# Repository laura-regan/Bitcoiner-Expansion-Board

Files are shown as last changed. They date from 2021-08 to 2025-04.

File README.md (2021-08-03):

# Bitcoiner Expansion Board

This repository contains the Altium Designer project for an expansion board for the [EBAZ4205](https://github.com/xjtuecho/EBAZ4205) bitcoin miner board which contains a Zynq 7010 SoC+FPGA. The purpose of the board is to expand the functionality of the bitcoin miner, allowing easy access to the Zynqs PL (Programmable Logic) pins via PMOD connectors and provide a HDMI output so that the board can be used for image processing research. The board also includes four switches and a two digit seven segment display to be used for debugging of the board and also to be used by students in a introductory digital design class. To facilitate programming and debugging of the FPGA and ARM processor a FT2232H based JTAG programmer was included on the board. The FT2232H chip has two channels and the second is used as a UART connection to allow communication between the ARM processor and a PC. 

The board also has a buck converter allowing it to be powered by a 12V power supply. A jump connector on the board allows the either USB or DC jack to be used as the power source.

The board has 4 layers and the stackup is the following:  
Layer 1: Signal  
Layer 2: GND  
Layer 3: GND  
Layer 4: Signal

Also included in the repository is a PDF of the schematic, PDFs of the PCB layout, a 3D PDF of the PCB, and the Gerber/NC Drill files for the PCB.

## PCB Renders
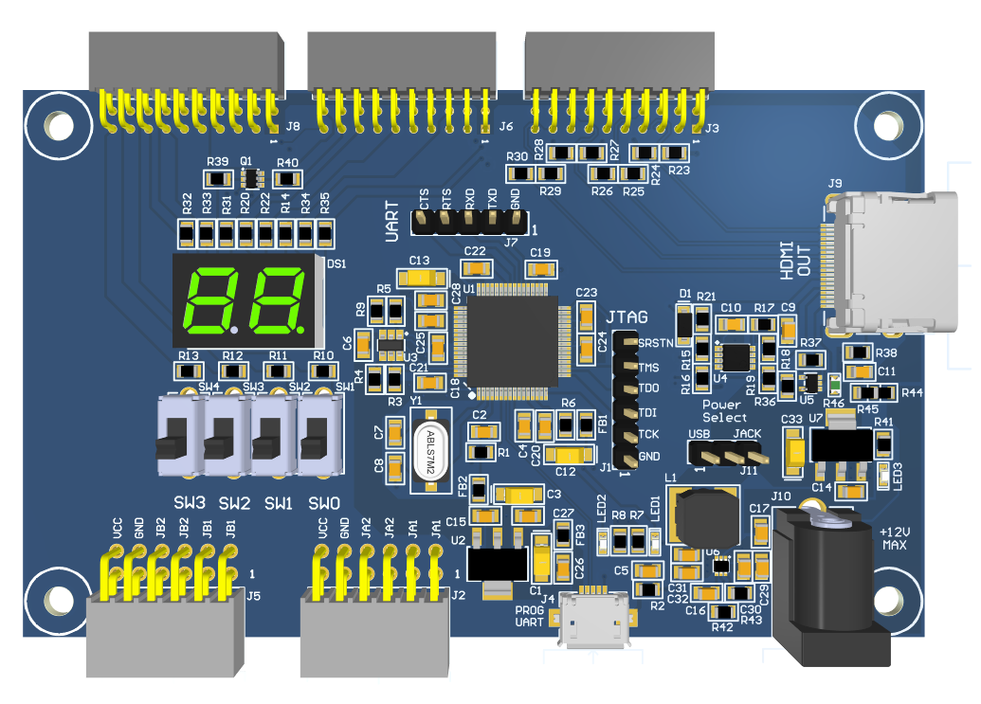
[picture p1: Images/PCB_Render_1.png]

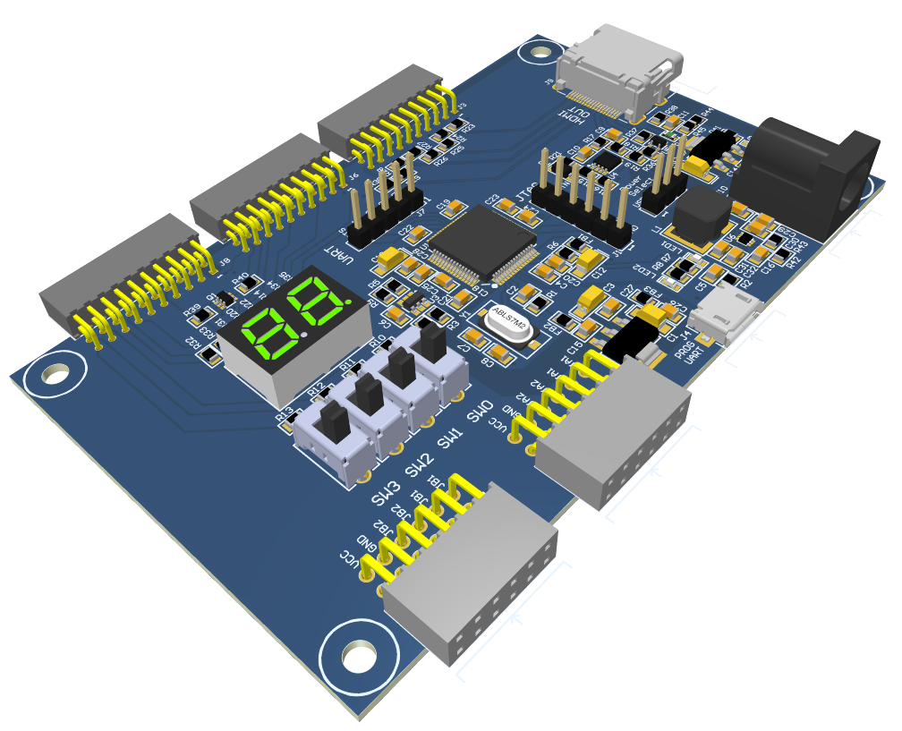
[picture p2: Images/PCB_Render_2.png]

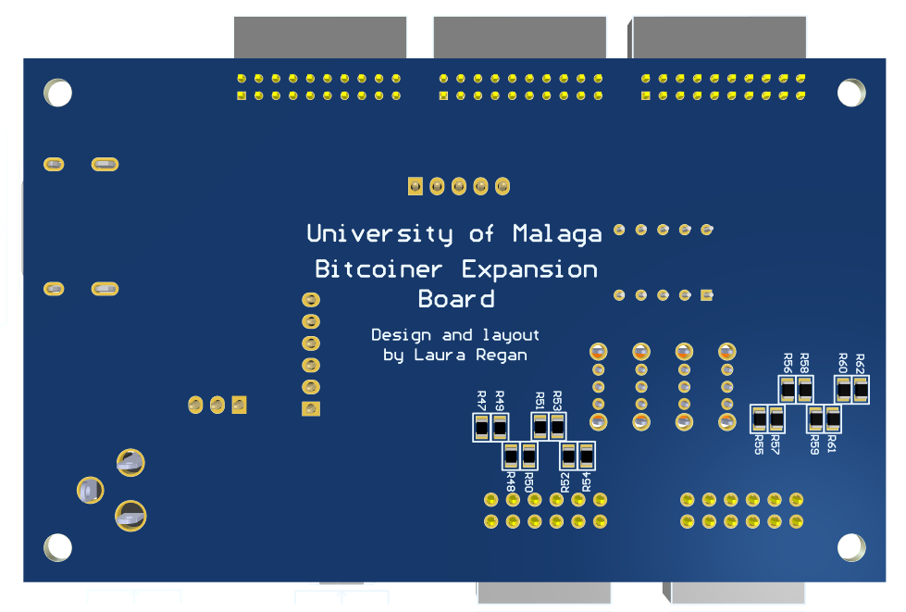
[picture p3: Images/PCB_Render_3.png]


## PCB Layout




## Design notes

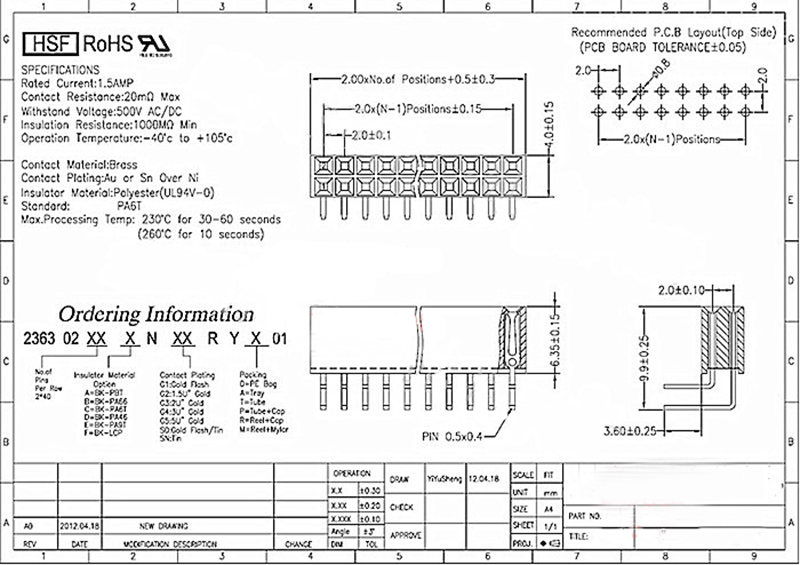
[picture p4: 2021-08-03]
Bitcoiner-Expansion-Board/Datasheets/Conector-Bitcoiner-2x10-2.0mm .jpg

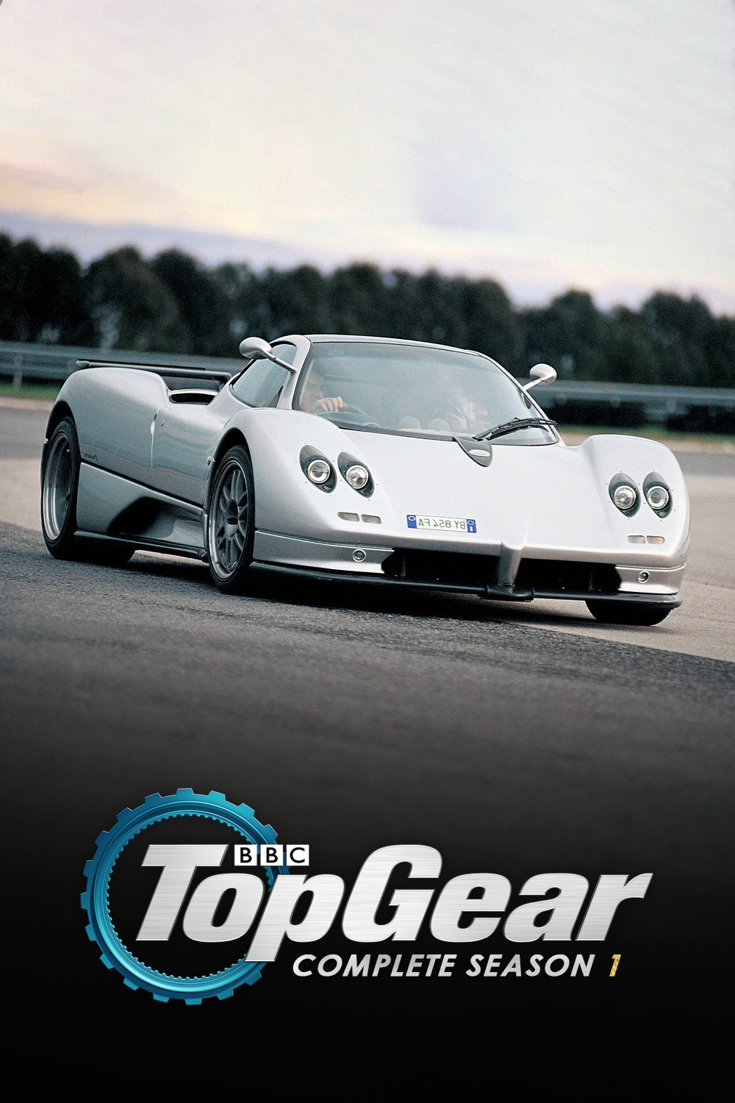
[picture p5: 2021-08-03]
Bitcoiner-Expansion-Board/Datasheets/Top Gear (2002) - Season 1.png

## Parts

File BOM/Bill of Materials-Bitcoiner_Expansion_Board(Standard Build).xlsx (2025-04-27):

Designator | Comment | Description | Manufacturer | Manufacturer Part Number | Quantity | Footprint
C1, C3, C12, C13, C33 | 4.7u / 16V | Tantalum capacitor 4.7 uF 16 VDC, T491A475K016AT, KEMET | KEMET | T491A475K016AT | 5 | C_TAN_A
C2, C4, C5, C6, C9, C10, C11, C16, C18, C19, C20, C21, C22, C23, C24, C25, C26, C27, C28, C30 | 100n | AVX - 08055C104KAT4A - Multilayer Ceramic Capacitor, 0.1 F, 10%, X7R, 50 V, 0805 [2012 Metric] RoHS Compliant: Yes | Kyocera AVX | 08055C104KAT4A | 20 | C0805
C7, C8 | 18p | Cap Ceramic 18pF 50V C0G 5% Pad SMD 0805 125°C Extreme Low ESR Bag | KEMET | C0805C180J5GAC | 2 | C0805
C14, C15 | 1u / 25V | Cap Ceramic 1uF 25V X7R 10% SMD 0805 125C Plastic T/R | KEMET | C0805C105K3RAC7210 | 2 | C0805
C17, C29 | 10u / 25V | CAP CER 10UF 25V X5R 0805 | Murata | GRM21BR61E106KA73K | 2 | C0805
C31, C32 | 22u / 10V | Cap Ceramic 22uF 10V X5R 20% SMD 0805 85C Cardboard T/R | Samsung | CL21A226MPCLRNC | 2 | C0805
D1 | BAS16GWJ | High-speed switching diode BAS16GW/SOD2/REEL 13 Q1/T1 S" | Nexperia | BAS16GWJ | 1 | SOD123
DS1 | LDD-E2802RD | Dual Digit 565 nm Green 0.28 inch Common Anode Seven Segment Display | Lumex | LDD-E2802RD | 1 | LDD-E2802RD
FB1, FB2, FB3 | 600R / 100MHz / 0.5A | TDK MMZ2012R601AT000 FERRITE BEAD, 0.2OHM, 500MA, 0805 | TDK | MMZ2012R601AT000 | 3 | R0805
J1 | HDR MALE 1x6 2.54MM |  | Amphenol | G800W302018EU | 1 | HDR_MALE_1X6_2.54MM
J2, J5 | SSW-106-02-T-D-RA | Connector | SAMTEC | SSW-106-02-T-D-RA | 2 | SSW-106-XX-YYY-D-RA
J3, J6, J8 | CON_2X10_2.0MM_RA |  |  |  | 3 | CON_2X10_2.0MM_RA
J4 | 10104111-0001LF | Conn USB Type A/B RCP 5 POS 0.65mm Solder RA SMD 5 Terminal 1 Port T/R | AMPHENOL ICC (FCI) | 10104111-0001LF | 1 | 101041110001LF
J7 | HDR MALE 1x5 2.54MM | HDR FEMALE 1x5 2.54MM | Amphenol ICC | 10129378-905001BLF | 1 | Hdr_Female_1x5_2.54mm
J9 | RAHHD19TR | HDMI Connector | Switchcraft Conxall | RAHHD19TR | 1 | RAHHD19TR
J10 | KLDX-0202-BC | Conn Power PIN 2 POS Solder RA Thru-Hole 3 Terminal 1 Port | Kycon | KLDX-0202-BC | 1 | KLDX-0202-BC
J11 | HDR 1x3 | HDR MALE 1x3 2.54MM | Amphenol | G800W305018EU | 1 | HDR_Male_1x3_2.54mm
L1 | 4.7u / 3.3A | Pwrind, SMT, Shld, Lrated / 6.0X6.0X4.5MM / Uom=ea / Wire Wound Inductive / Fixed Inductor | Laird Steward | TYS60454R7M-10 | 1 | TYS6045
LED1, LED2, LED3 | Amber | LED Uni-Color Amber 609nm Automotive 2-Pin Chip 0603(1608Metric) T/R | Inolux | IN-S63AT5A | 3 | LED0603
LINK1 | LINK | CONN SHUNT 2POS OPEN 2.54MM | TE Connectivity | 382811-8 | 1
Q1 | BC857BS,115 | NEXPERIA - BC857BS,115 - TRANSISTOR, DUAL, PNP, SC-88 | Nexperia | BC857BS,115 | 1 | SOT363
R1 | 12k | Res Thick Film 0805 12K Ohm 1% 0.125W(1/8W) ±100ppm/C Molded SMD Paper T/R | Yageo | RC0805FR-0712KL | 1 | R0805
R2, R3, R4, R5, R6, R10, R11, R12, R13, R36, R43 | 10k | RES SMD 10K OHM 1% 1/8W 0805 | Yageo | RC0805FR-0710KL | 11 | R0805
R7, R8, R41 | 470R | Res Thick Film 0805 470 Ohm 1% 1/8W +/-100ppm/ßC Molded SMD Paper T/R | Yageo | RC0805FR-07470RL | 3 | R0805
R9 | 2k | Res Thick Film 0805 2K Ohm 1% 1/8W 100ppm/C Molded SMD SMD Paper T/R | Yageo | RC0805FR-102KL | 1 | R0805
R14, R20, R22, R31, R32, R33, R34, R35 | 200R | Res Thick Film 2.0 x 1.2 mm 200 Ohm 1% 0.125W(1/8W) 100ppm/ C Molded SMD Paper T/R | Yageo | RC0805FR-07200RL | 8 | R0805
R15, R16, R18, R19 | 1.5k | Res Thick Film 0805 1.5K Ohm 1% 0.125W(1/8W) ±100ppm/C Molded SMD Paper T/R | Yageo | RC0805FR-071K5L | 4 | R0805
R17 | 200k | YAGEO - RC0805FR-07200KL - RES, THICK FILM, 200K, 1%, 0.125W, 0805, REEL | Yageo | RC0805FR-07200KL | 1 | R0805
R21 | 27k | Chip Resistor Precision Grade Thick Film 0805 27kOhm 1% Paper T/R | Yageo | RE0805FRE0727KL | 1 | R0805
R37 | 100k | YAGEO RC0805FR-07100KL RES, THICK FILM, 100K, 1%, 0.125W, 0805, REEL | Yageo | RC0805FR-07100KL | 1 | R0805
R38 | 1M | Res Thick Film 0805 1M Ohm 1% 0.125W(1/8W) ±100ppm/C Epoxy SMD T/R | Yageo Phycomp | RC0805FR-071ML | 1 | R0805
R39, R40 | 2.2k | RESISTOR, THICK FILM, 2.2KOHM, 125mW, 1%, FULL REEL | Yageo | RC0805FR-072K2L | 2 | R0805
R42 | 52.3k | Res Thick Film 0805 52.3K Ohm 1% 1/8W ±100ppm/°C Molded SMD SMD Paper Tape on Plastic Reel | Bourns | CR0805-FX-5232ELF | 1 | R0805
R45 | 0R | Res Thick Film 0805 0 Ohm Epoxy Pad SMD T/R | Yageo | RC0805FR-070RL | 1 | R0805
R46 | 0ZCM0012FF2G | PTC RESET FUSE 9V 120MA 0603 | Bel | 0ZCM0012FF2G | 1 | 0ZCM0012FF2G
R47, R48, R49, R50, R51, R52, R53, R54, R55, R56, R57, R58, R59, R60, R61, R62 | 200R | RES SMD 200 OHM 1% 1/10W 0603 | Panasonic | ERJ-3EKF2000V | 16 | R0603
SW1, SW2, SW3, SW4 | OS102011MS2QN1 | Slide | ITT C&K | OS102011MS2QN1 | 4 | OS102011MS2QN1
U1 | FT2232HL-REEL | Integrated Circuit | FTDI Chip | FT2232HL-REEL | 1 | QFP50P1200X1200X160-64N
U2, U7 | MCP1825ST-3302E/DB | IC REG LIN 3.3V 500MA SOT223-3 | Microchip | MCP1825ST-3302E/DB | 2 | SOT-223-3
U3 | 93LC56BT-I/OT | MICROCHIP - 93LC56BT-I/OT. - 2K, 128 X 16, SERIAL EE, IND ROHS COMPLIANT: YES | Microchip | 93LC56BT-I/OT | 1 | SOT-23-6
U4 | LSF0102DPH |  | Nexperia | LSF0102DPH | 1 | SOT505-2
U5 | 74LVC1G07GW,125 | NEXPERIA - 74LVC1G07GW,125 - BUFFER, NON-INVERTING, TSSOP-5 | Nexperia | 74LVC1G07GW,125 | 1 | SOT353-1
U6 | TPS562202SDRLR |  | Texas Instruments | TPS562202SDRLR | 1 | SOT563-6
Y1 | ABLS7M2-12.000MHZ-D2Y-T | CRYSTAL 12.0000MHZ 18PF SMD | Abracon | ABLS7M2-12.000MHZ-D-2Y-T | 1 | ABLS7M2-12.000MHZ-D2Y-T

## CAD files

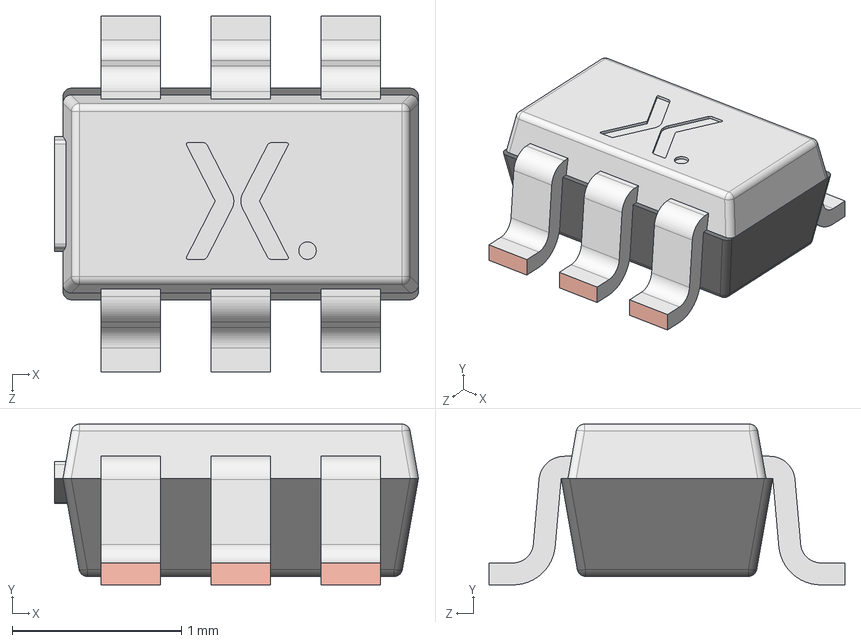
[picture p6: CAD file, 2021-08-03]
Bitcoiner-Expansion-Board/3D models/SOT363.step
2.15 x 0.95 x 2.10 mm
SOT353 Lower body
SOT353 Lead x 6
SOT353 Upper body

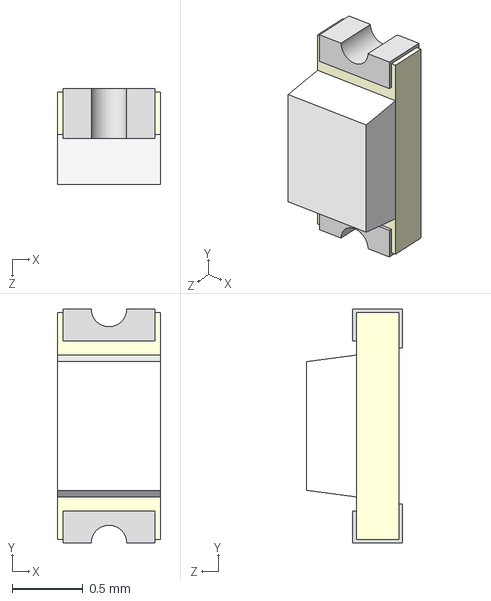
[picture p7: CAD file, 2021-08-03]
Bitcoiner-Expansion-Board/3D models/LED SMD0603.step
0.725 x 1.65 x 0.675 mm

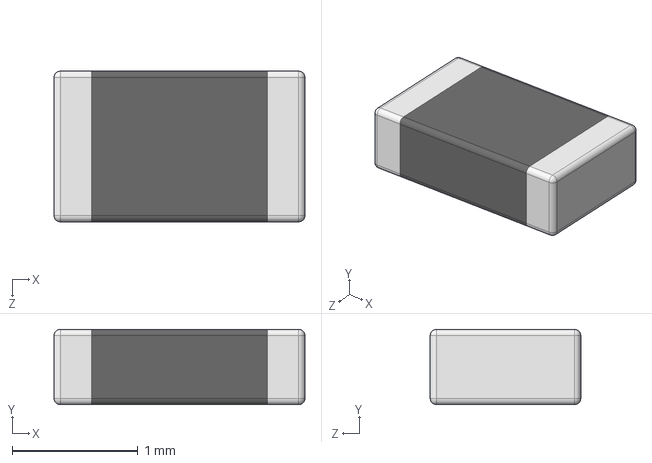
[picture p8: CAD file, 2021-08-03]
Bitcoiner-Expansion-Board/3D models/RESC2012X60N EIA 0805.step
2.00 x 0.6 x 1.20 mm

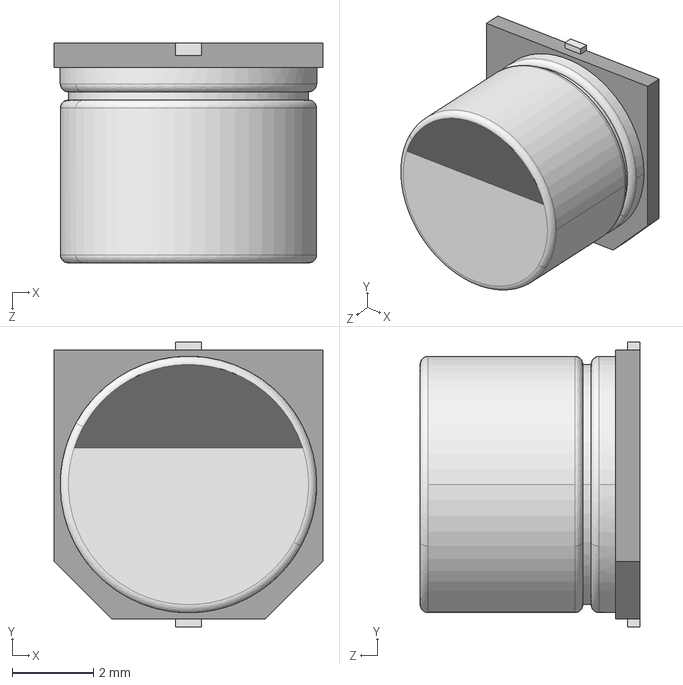
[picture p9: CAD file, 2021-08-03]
Bitcoiner-Expansion-Board/3D models/CAPAE_D.STEP
6.60 x 7.00 x 5.41 mm

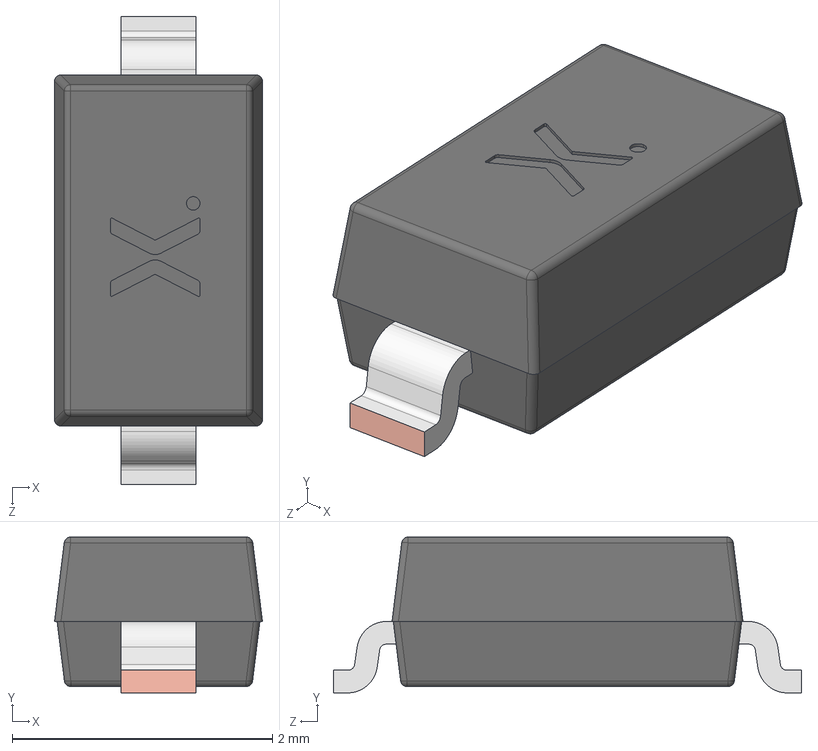
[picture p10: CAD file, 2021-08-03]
Bitcoiner-Expansion-Board/3D models/SOD123.step
1.60 x 1.20 x 3.60 mm
SOD123 LF
SOD123 Lower mold
SOD123 Upper mold

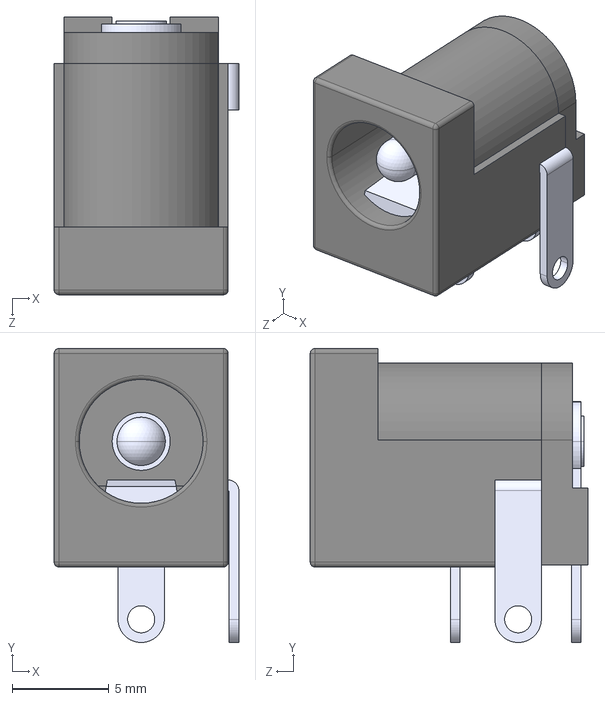
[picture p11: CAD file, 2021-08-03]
Bitcoiner-Expansion-Board/3D models/KLDX-0202-BC.STEP
9.55 x 15.2 x 14.4 mm

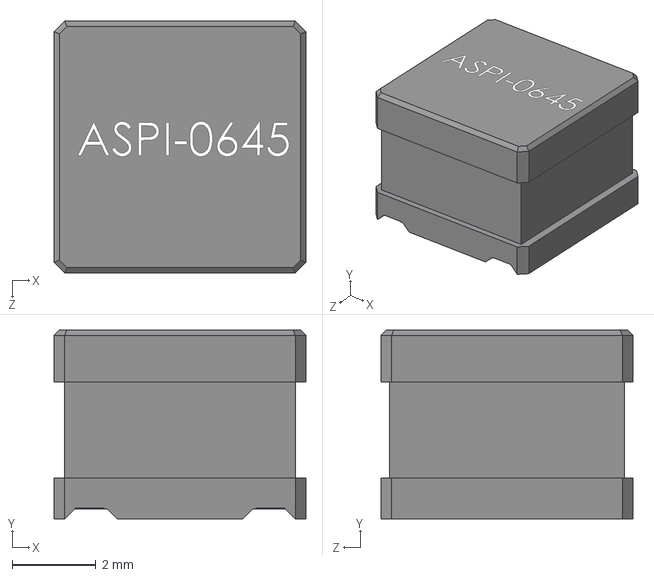
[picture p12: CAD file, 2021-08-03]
Bitcoiner-Expansion-Board/3D models/ASPI-0645.STEP
6.00 x 4.50 x 6.00 mm

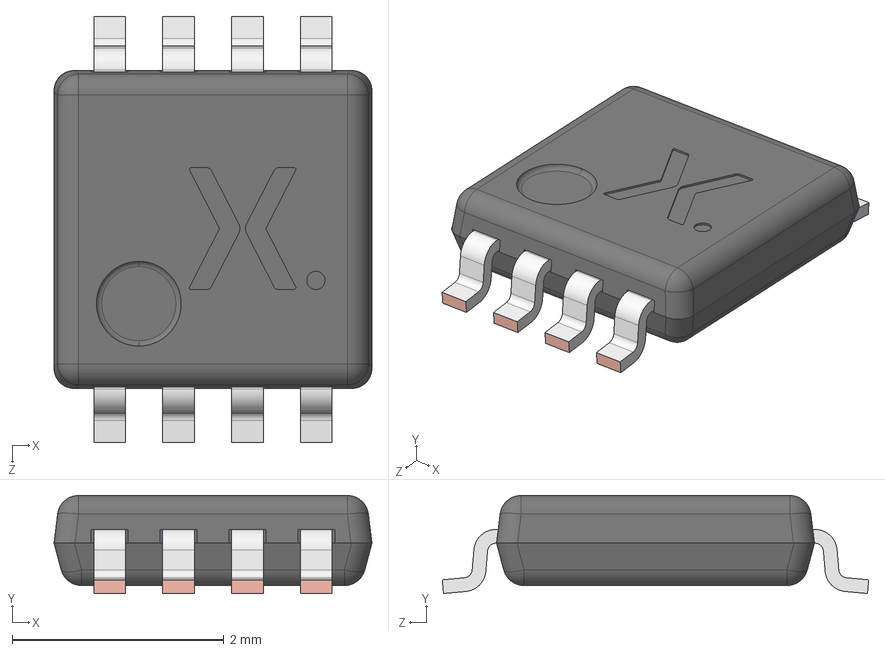
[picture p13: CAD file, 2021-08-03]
Bitcoiner-Expansion-Board/3D models/SOT505-2.step
3.00 x 0.925 x 4.02 mm
SOT505-2 Lower mold body
SOT505 Lead x 8
SOT505-2 Upper mold body

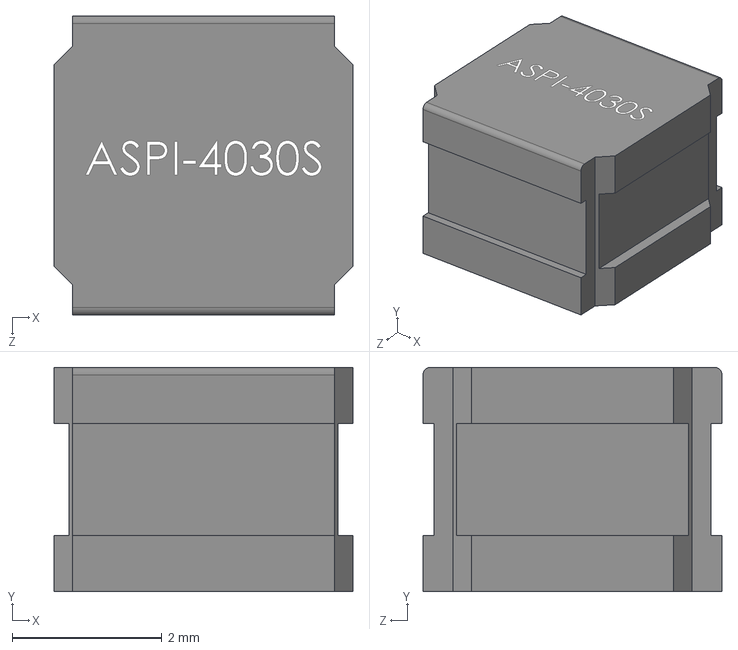
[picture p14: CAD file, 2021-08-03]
Bitcoiner-Expansion-Board/3D models/ASPI-4030S.STEP
4.00 x 3.00 x 4.00 mm

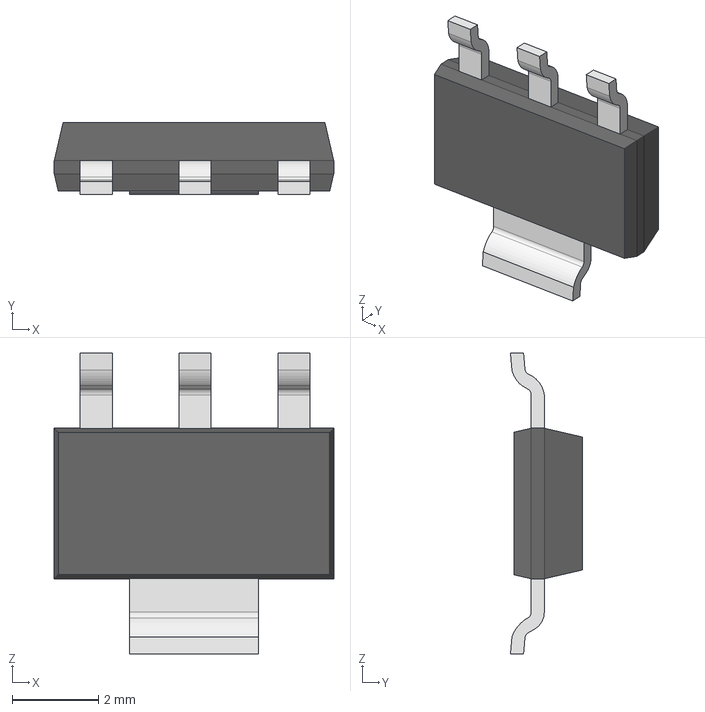
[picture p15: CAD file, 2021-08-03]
Bitcoiner-Expansion-Board/3D models/SOT-223-3.stp
6.50 x 1.68 x 7.00 mm

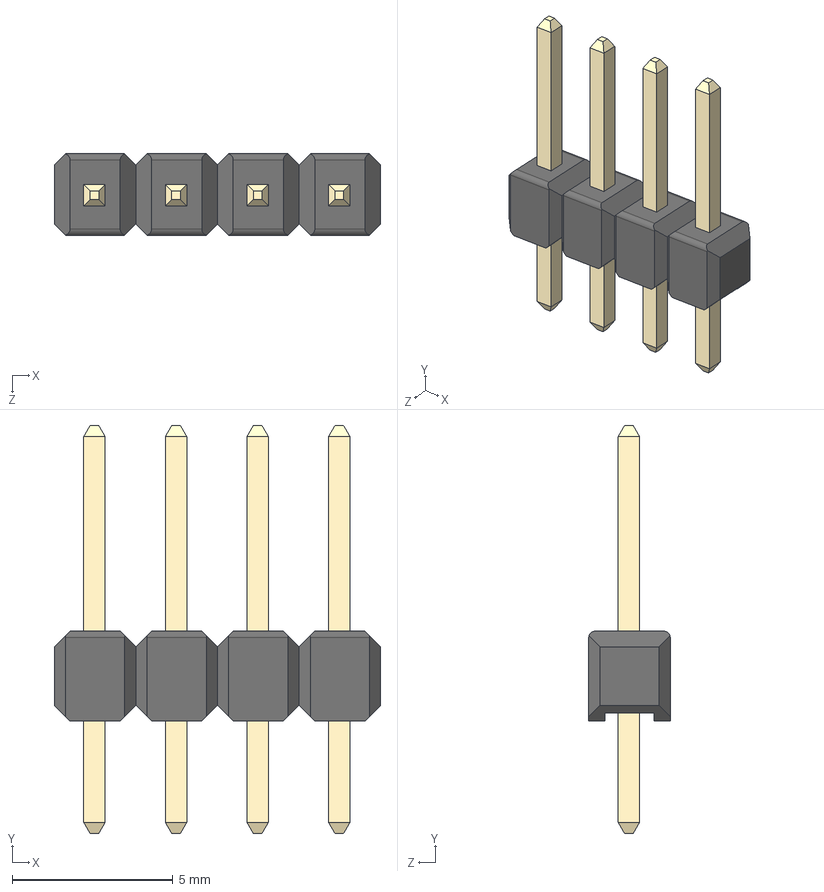
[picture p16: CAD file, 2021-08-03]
Bitcoiner-Expansion-Board/3D models/HEADER_4PINS_2.54MM.STEP
10.2 x 12.7 x 2.54 mm
holder
pin x 4

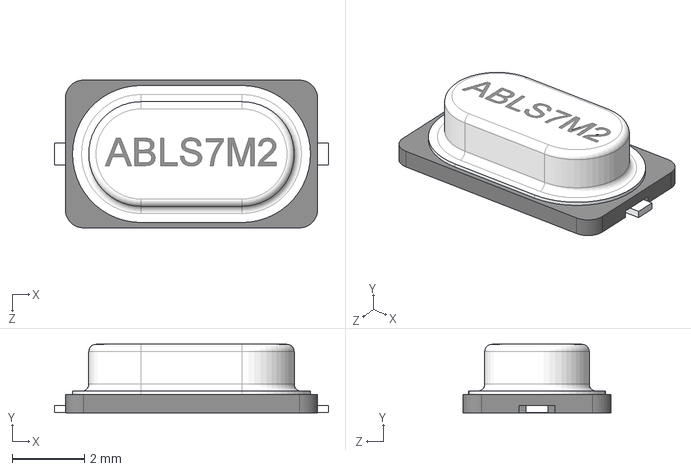
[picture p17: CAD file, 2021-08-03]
Bitcoiner-Expansion-Board/3D models/ABLS7M2.STEP
7.60 x 1.90 x 4.10 mm

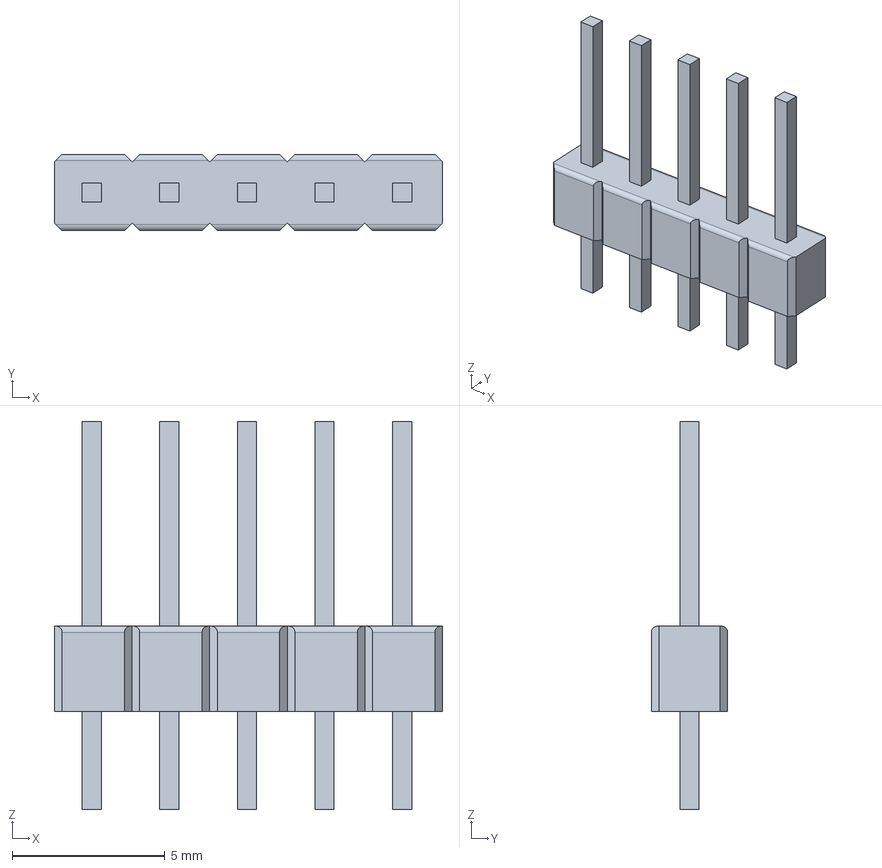
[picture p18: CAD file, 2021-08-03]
Bitcoiner-Expansion-Board/3D models/c-826629-5-r-3d.stp
12.7 x 2.50 x 12.7 mm

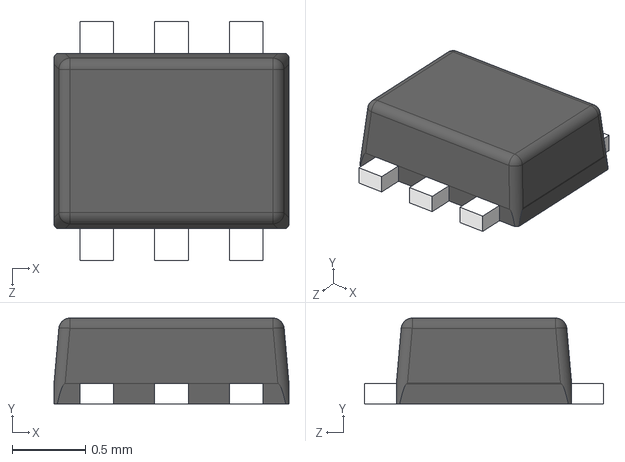
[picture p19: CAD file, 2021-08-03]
Bitcoiner-Expansion-Board/3D models/SOT-563.step
1.60 x 0.584 x 1.63 mm

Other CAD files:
Bitcoiner-Expansion-Board/3D models/ABL.STEP
Bitcoiner-Expansion-Board/3D models/T491A475K016AT.step
Bitcoiner-Expansion-Board/3D models/vls6045ex.step
Bitcoiner-Expansion-Board/3D models/SSW-106-02-T-D-RA.stp
Bitcoiner-Expansion-Board/3D models/10104111C.stp
Bitcoiner-Expansion-Board/3D models/1827059-1.stp
Bitcoiner-Expansion-Board/3D models/1x4 TH Pitch 2_54mm.STEP
Bitcoiner-Expansion-Board/3D models/403A-03.STEP
Bitcoiner-Expansion-Board/3D models/CAPC2012X94N EIA 0805.step
Bitcoiner-Expansion-Board/3D models/DO-219AB.stp
Bitcoiner-Expansion-Board/3D models/DPAK.step
Bitcoiner-Expansion-Board/3D models/EDH106M025A9BAA.step
Bitcoiner-Expansion-Board/3D models/HEADER_3PINS_2.54MM.STEP
Bitcoiner-Expansion-Board/3D models/Inductor SMD 7850.stp
Bitcoiner-Expansion-Board/3D models/LTD-2601G.step
Bitcoiner-Expansion-Board/3D models/OS102011MS2QN1.step
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

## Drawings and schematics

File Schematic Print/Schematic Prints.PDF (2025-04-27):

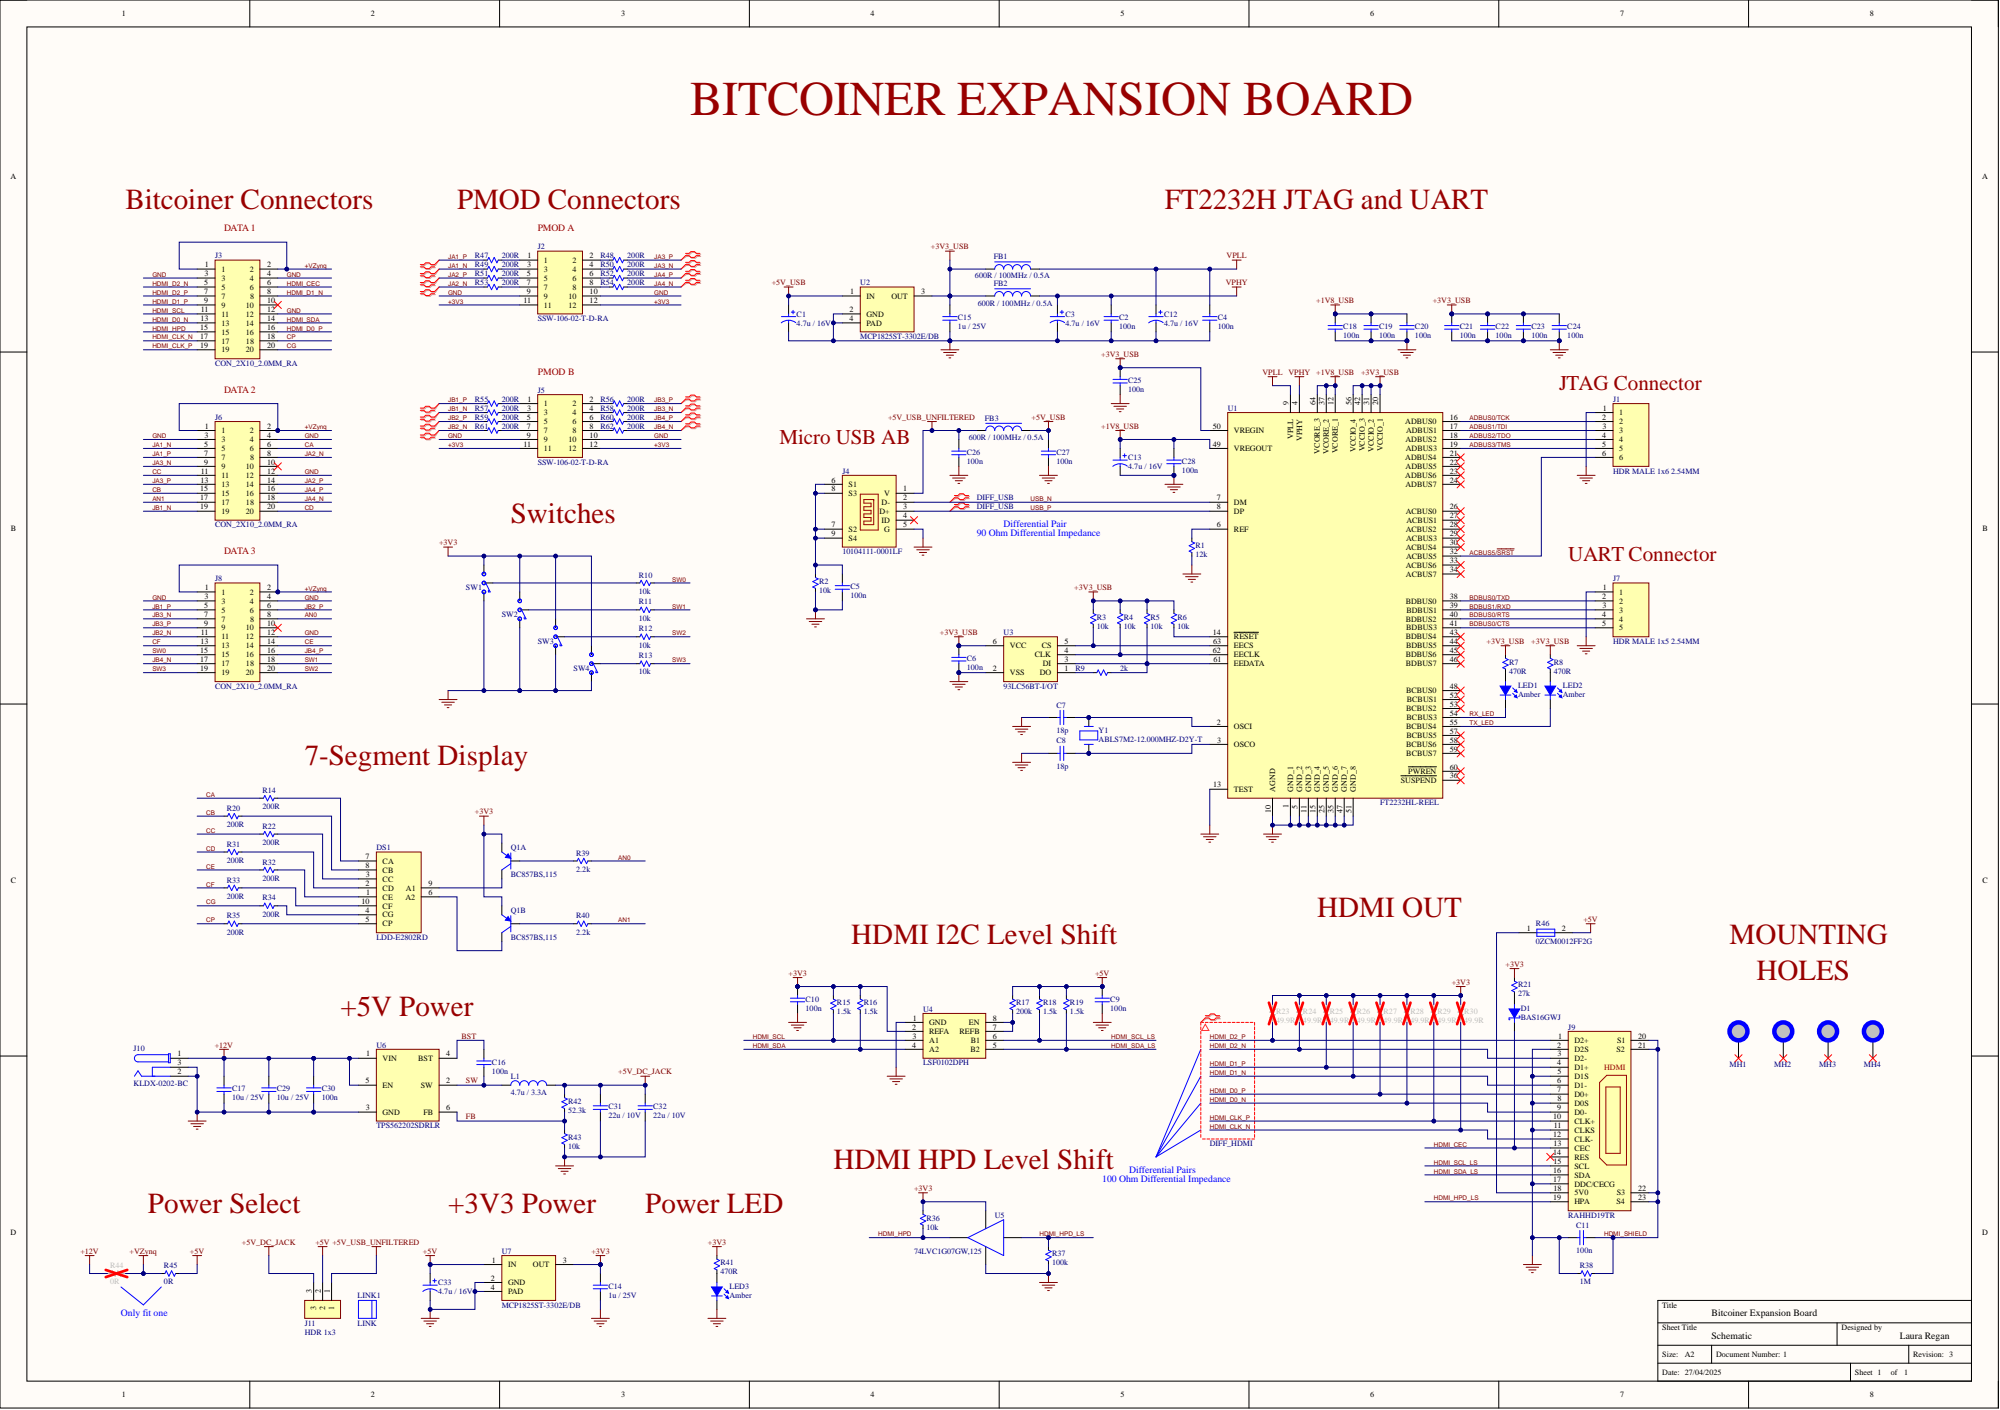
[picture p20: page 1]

1 | CD 2 CC 3

CLK- 12
CEC 13 RES 14

HDMI HPD Level Shift

Sheet Title Schemati c | Designed by Laura Regan

Size: A2 | Document Number: 1 | Revision: 3

Date: 27/04/2025 | Sheet 1 of 1

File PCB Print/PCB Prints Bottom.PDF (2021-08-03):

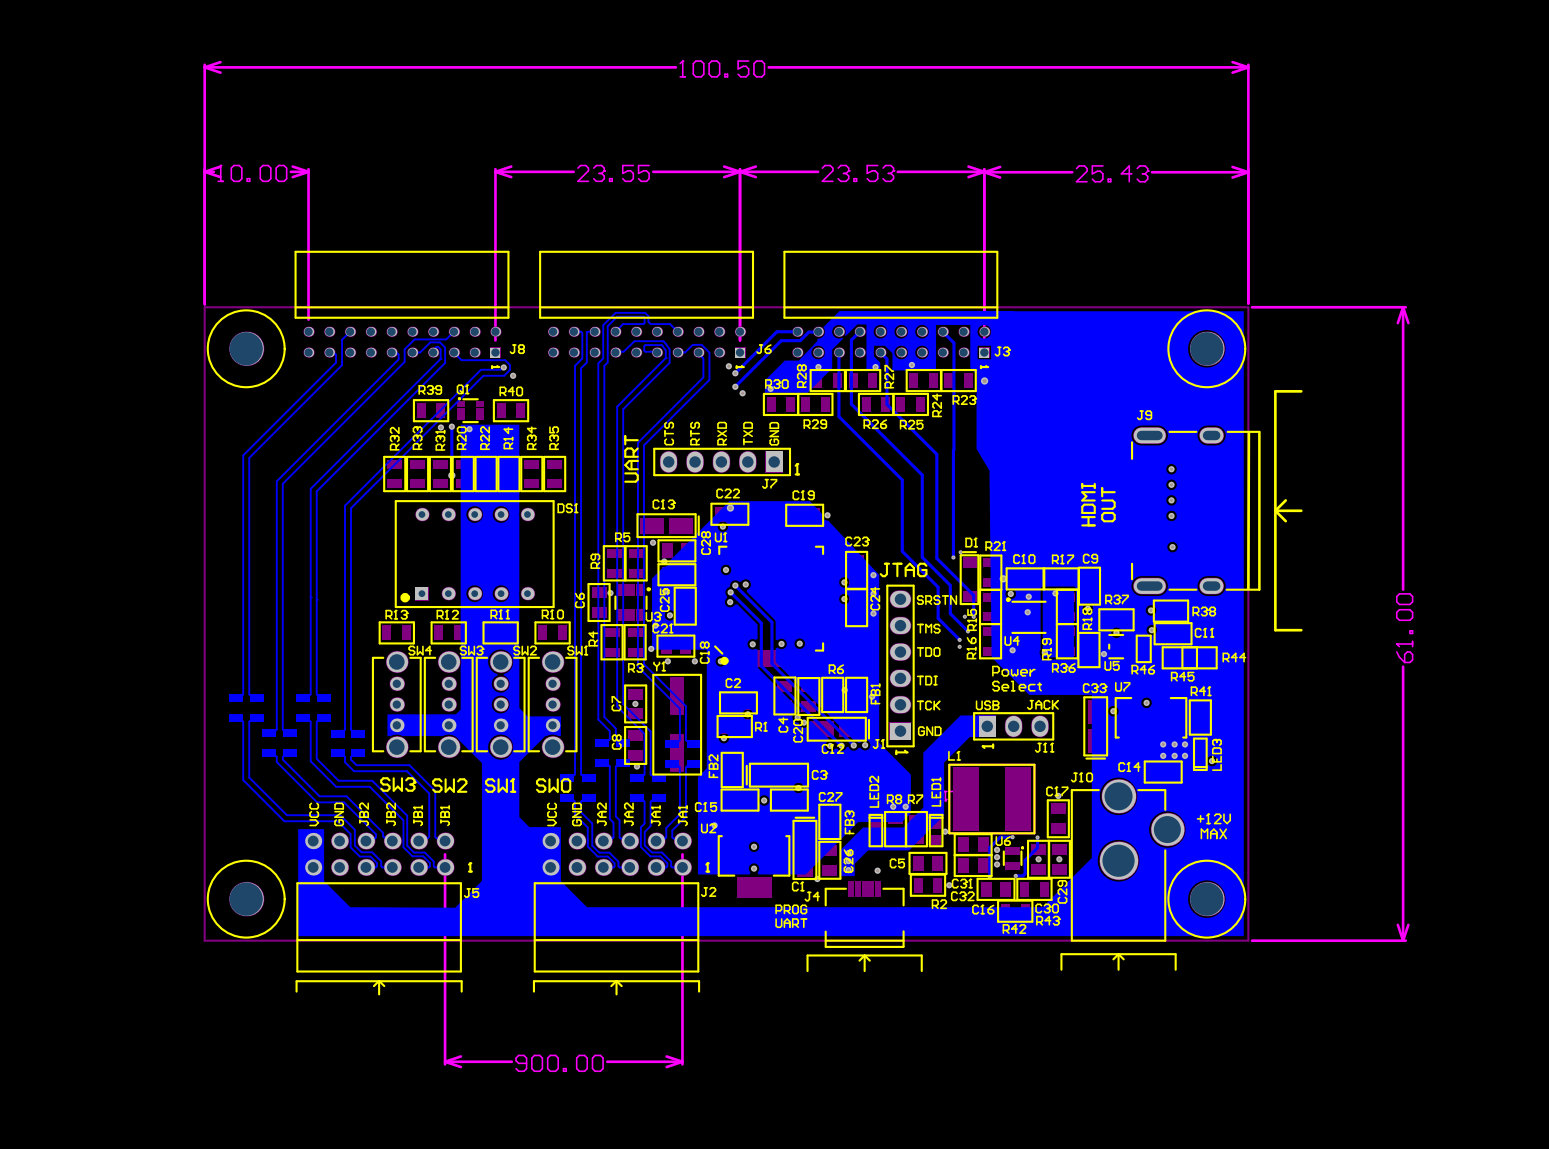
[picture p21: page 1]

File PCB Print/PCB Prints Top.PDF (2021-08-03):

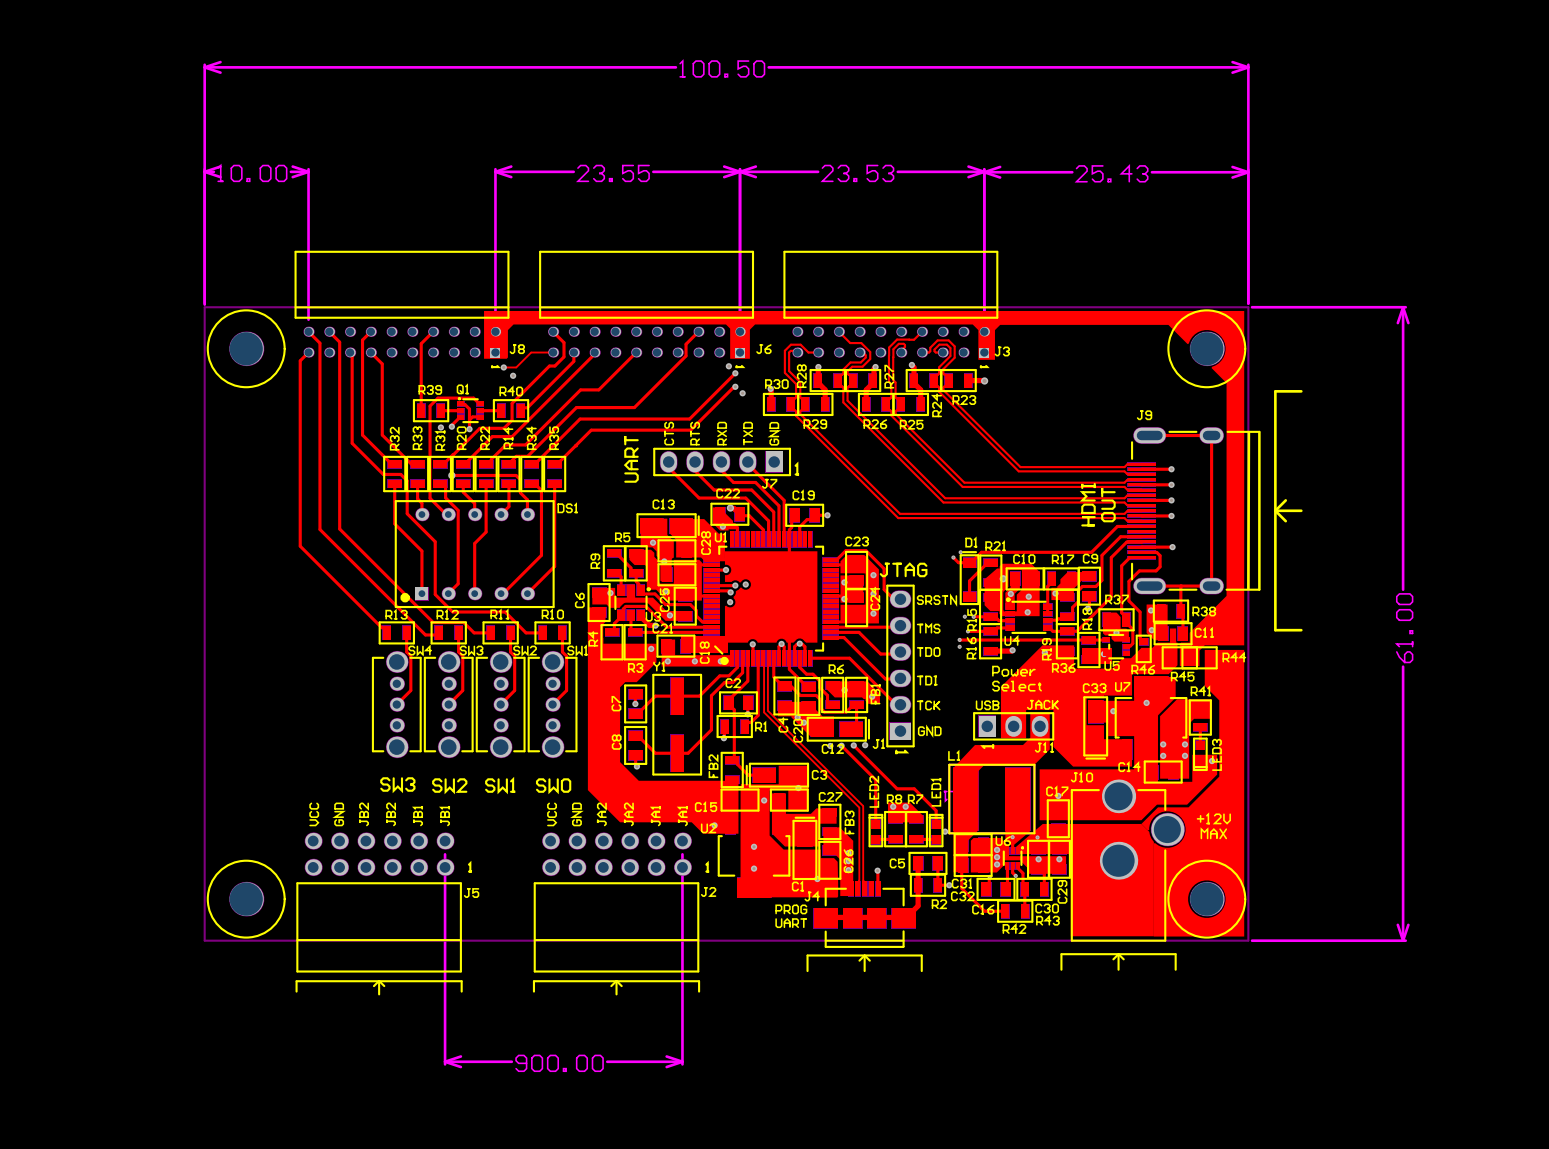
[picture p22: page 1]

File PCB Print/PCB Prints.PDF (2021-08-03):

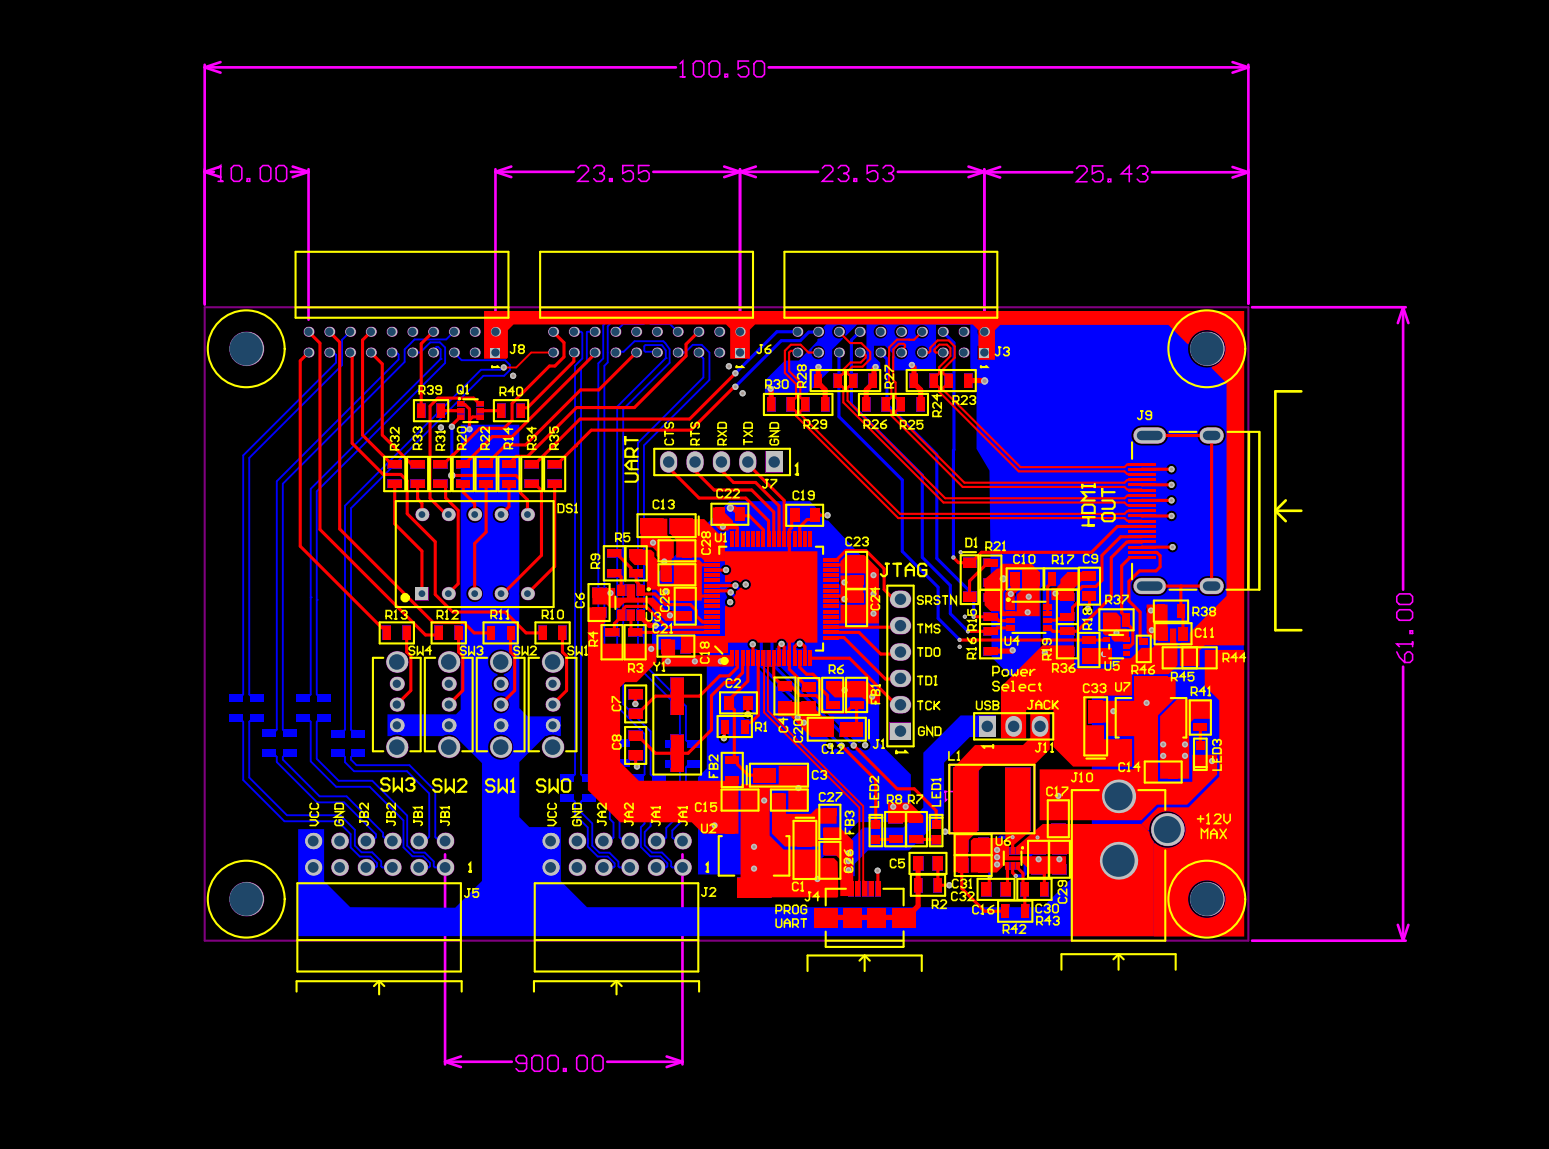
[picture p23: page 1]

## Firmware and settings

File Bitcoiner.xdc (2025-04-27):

# ----------------------------------------------------------------------------
# JA Pmod - Bank 35
# ----------------------------------------------------------------------------
set_property PACKAGE_PIN G19 [get_ports {JA1_P}];  # "JA1_P - AD13_P"
set_property PACKAGE_PIN G20 [get_ports {JA1_N}];  # "JA1_N - AD13_N"
set_property PACKAGE_PIN J20 [get_ports {JA2_P}];  # "JA2_P - AD5_P"
set_property PACKAGE_PIN H20 [get_ports {JA2_N}];  # "JA2_N - AD5_N"
set_property PACKAGE_PIN K19 [get_ports {JA3_P}];  # "JA3_P - AD11_P"
set_property PACKAGE_PIN J19 [get_ports {JA3_N}];  # "JA3_N - AD11_N"
set_property PACKAGE_PIN L19 [get_ports {JA4_P}];  # "JA4_P - AD3_P"
set_property PACKAGE_PIN L20 [get_ports {JA4_N}];  # "JA4_N - AD3_N"

# ----------------------------------------------------------------------------
# JB Pmod - Bank 35 and Bank 34
# ----------------------------------------------------------------------------
set_property PACKAGE_PIN M19 [get_ports {JB1_P}];  # "JB1_P - AD2_P"
set_property PACKAGE_PIN M20 [get_ports {JB1_N}];  # "JB1_N - AD2_N"
set_property PACKAGE_PIN N20 [get_ports {JB2_P}];  # "JB2_P"
set_property PACKAGE_PIN P20 [get_ports {JB2_N}];  # "JB2_N"
set_property PACKAGE_PIN N17 [get_ports {JB3_P}];  # "JB3_P"
set_property PACKAGE_PIN P18 [get_ports {JB3_N}];  # "JB3_N"
set_property PACKAGE_PIN T20 [get_ports {JB4_P}];  # "JB4_P"
set_property PACKAGE_PIN U20 [get_ports {JB4_N}];  # "JB4_N"

# ----------------------------------------------------------------------------
# Switches - Bank 35 and Bank 34
# ----------------------------------------------------------------------------
set_property -dict {PACKAGE_PIN P19  IOSTANDARD LVCMOS33} [get_ports {SW[0]}];  # "SW[0]"
set_property -dict {PACKAGE_PIN T19  IOSTANDARD LVCMOS33} [get_ports {SW[1]}];  # "SW[1]"
set_property -dict {PACKAGE_PIN U19  IOSTANDARD LVCMOS33} [get_ports {SW[2]}];  # "SW[2]"
set_property -dict {PACKAGE_PIN V20  IOSTANDARD LVCMOS33} [get_ports {SW[3]}];  # "SW[3]"

# ----------------------------------------------------------------------------
# 7-Segment Display - Bank 35 and Bank 34
# ----------------------------------------------------------------------------
set_property -dict {PACKAGE_PIN M17  IOSTANDARD LVCMOS33} [get_ports {ANODE[0]}];  # "AN0"
set_property -dict {PACKAGE_PIN M18  IOSTANDARD LVCMOS33} [get_ports {ANODE[1]}];  # "AN1"
set_property -dict {PACKAGE_PIN J18  IOSTANDARD LVCMOS33} [get_ports {CATHODE[0]}];   # "CA"
set_property -dict {PACKAGE_PIN L16  IOSTANDARD LVCMOS33} [get_ports {CATHODE[1]}];   # "CB"
set_property -dict {PACKAGE_PIN K18  IOSTANDARD LVCMOS33} [get_ports {CATHODE[2]}];   # "CC"
set_property -dict {PACKAGE_PIN L17  IOSTANDARD LVCMOS33} [get_ports {CATHODE[3]}];   # "CD"
set_property -dict {PACKAGE_PIN R19  IOSTANDARD LVCMOS33} [get_ports {CATHODE[4]}];   # "CE"
set_property -dict {PACKAGE_PIN R18  IOSTANDARD LVCMOS33} [get_ports {CATHODE[5]}];   # "CF"
set_property -dict {PACKAGE_PIN K17  IOSTANDARD LVCMOS33} [get_ports {CATHODE[6]}];   # "CG"
set_property -dict {PACKAGE_PIN E19  IOSTANDARD LVCMOS33} [get_ports {CATHODE[7]}];   # "CP"

# ----------------------------------------------------------------------------
# HDMI Out - Bank 35 and Bank 34
# ----------------------------------------------------------------------------
#set_property -dict { PACKAGE_PIN B19  IOSTANDARD TMDS_33 } [get_ports {HDMI_D2_P}];   # "HDMI_D2_P"
#set_property -dict { PACKAGE_PIN A20  IOSTANDARD TMDS_33 } [get_ports {HDMI_D2_N}];   # "HDMI_D2_N"
#set_property -dict { PACKAGE_PIN C20  IOSTANDARD TMDS_33 } [get_ports {HDMI_D1_P}];   # "HDMI_D1_P"
#set_property -dict { PACKAGE_PIN B20  IOSTANDARD TMDS_33 } [get_ports {HDMI_D1_N}];   # "HDMI_D1_N"
#set_property -dict { PACKAGE_PIN D19  IOSTANDARD TMDS_33 } [get_ports {HDMI_D0_P}];   # "HDMI_D0_P"
#set_property -dict { PACKAGE_PIN D20  IOSTANDARD TMDS_33 } [get_ports {HDMI_D0_N}];   # "HDMI_D0_N"
#set_property -dict { PACKAGE_PIN F19  IOSTANDARD TMDS_33 } [get_ports {HDMI_CLK_P}];  # "HDMI_CLK_P"
#set_property -dict { PACKAGE_PIN F20  IOSTANDARD TMDS_33 } [get_ports {HDMI_CLK_N}];  # "HDMI_CLK_N"
#set_property PACKAGE_PIN H16 [get_ports {HDMI_CEC}];    # "HDMI_CEC"
#set_property PACKAGE_PIN H17 [get_ports {HDMI_SCL}];    # "HDMI_SCL"
#set_property PACKAGE_PIN D18 [get_ports {HDMI_SDA}];    # "HDMI_SDA"
#set_property PACKAGE_PIN H18 [get_ports {HDMI_HPD}];    # "HDMI_HPD"
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

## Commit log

2025-04-27 - Correct pinout on power jack - Correct connection of EEPROM DI and DO pins - Rotate switches so that the up position corresponds to a logical one - Update revision to B.3. - Minor schematic correct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
    [Bitcoiner_EB_Project_V1I1.PcbLib, Bitcoiner_EB_Project_V1I1.SchLib, Bitcoiner_EB_Project_V1I1_Schematic.SchDoc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]
2025-04-27 - Generate manufacturing data
    [Bill of Materials-Bitcoiner_Expansion_Board(Standard Build).xlsx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]
